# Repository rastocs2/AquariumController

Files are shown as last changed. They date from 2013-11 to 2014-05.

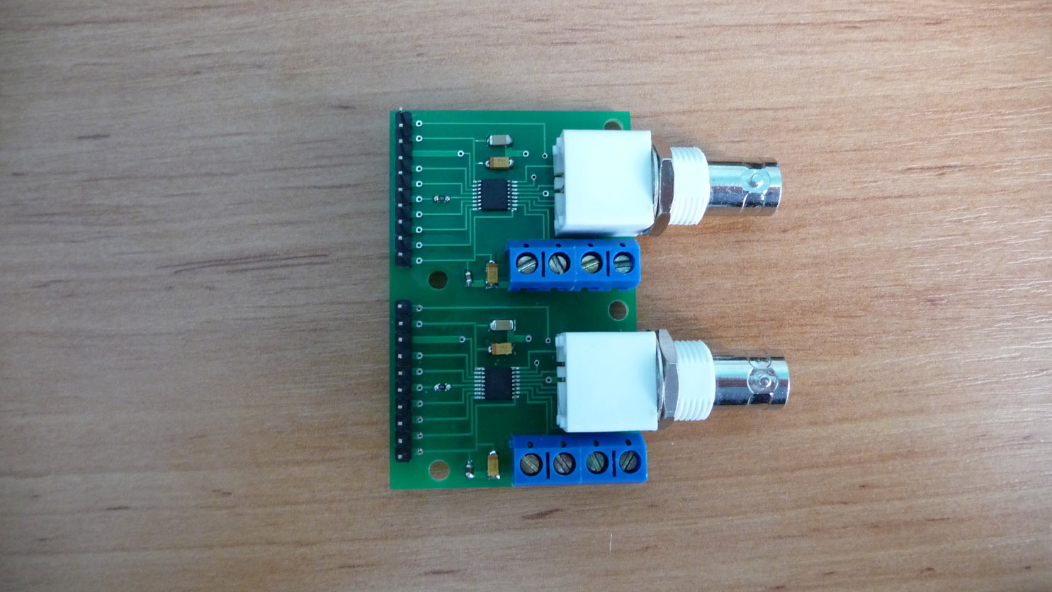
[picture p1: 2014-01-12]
Pics/pH_orp_module.jpg

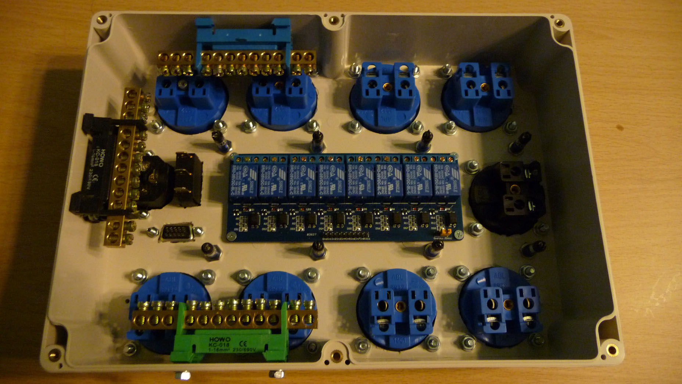
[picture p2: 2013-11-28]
Pics/power2.jpg

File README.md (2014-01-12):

AquariumController
==================

Aquarium controller based on Arduino and 4D Systems Intelligent Display Module.

## Components

1. Arduino Mega 2560 R3 (http://arduino.cc/en/Main/ArduinoBoardMega2560)
2. 4D Systems µLCD-28PTU (http://www.4dsystems.com.au/product/1/8/4D_Intelligent_Display_Modules/uLCD_28PTU/)
3. Real Time Clock Module DS3231 - it is much more accurate than DS1307 (http://www.ebay.com/sch/i.html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)
4. 8 Channel 5V Opto-Isolated Relay Module Shield (http://www.ebay.com/sch/i.html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)
5. Digital Temperature Sensor DS18B20 (http://www.ebay.com/sch/i.html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)
6. pH module based on LMP91200 (http://www.ti.com/product/lmp91200)
7. ORP module based on LMP91200 (http://www.ti.com/product/lmp91200)
8. WiFi module based on CC3000 (http://www.ti.com/product/cc3000) - will finished in version 3.0

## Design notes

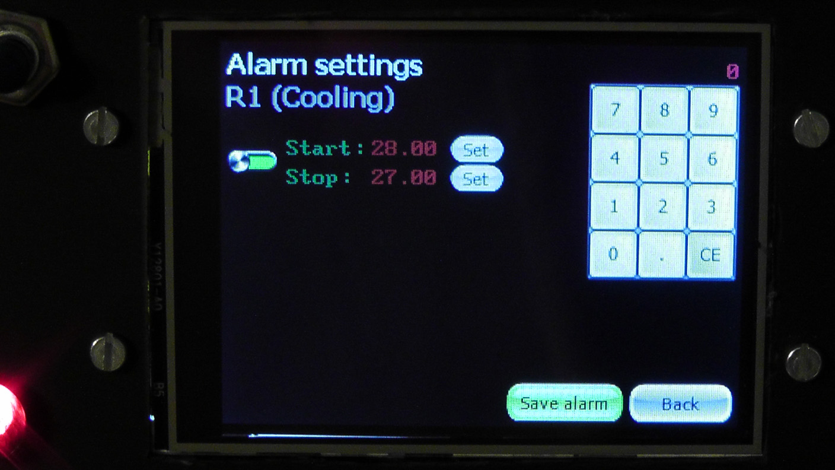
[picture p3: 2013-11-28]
Pics/lcd3.jpg

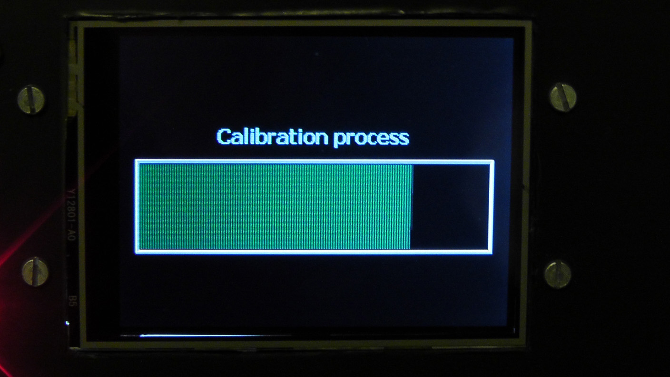
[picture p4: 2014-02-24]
Pics/lcd6.jpg

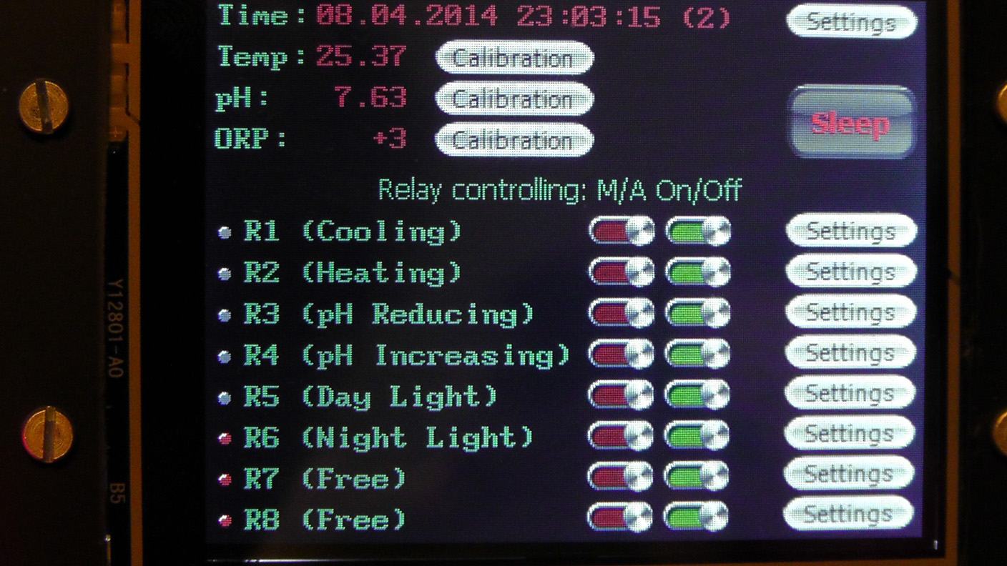
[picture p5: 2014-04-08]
Pics/lcd1.jpg

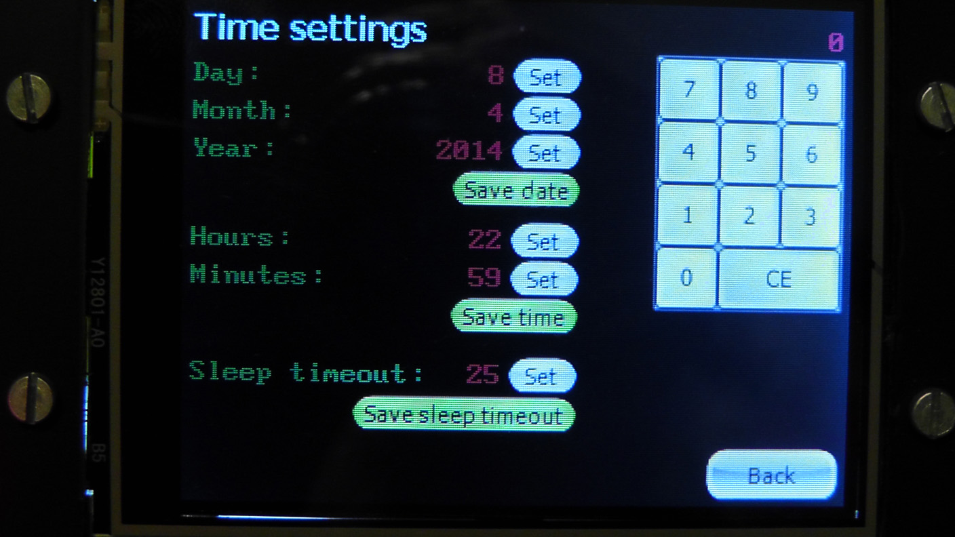
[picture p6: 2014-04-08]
Pics/lcd2.jpg

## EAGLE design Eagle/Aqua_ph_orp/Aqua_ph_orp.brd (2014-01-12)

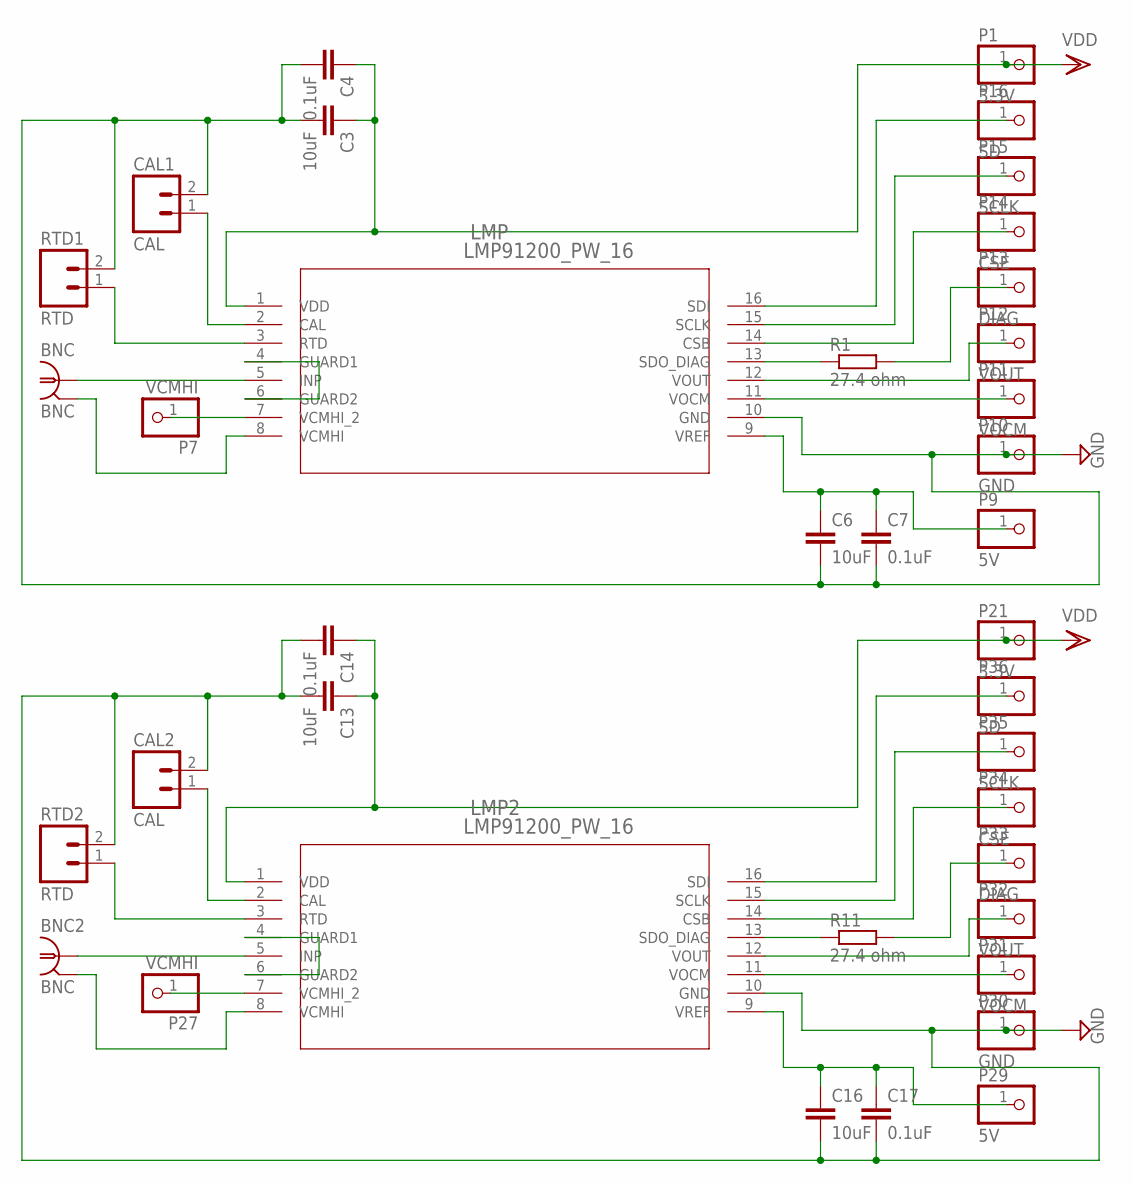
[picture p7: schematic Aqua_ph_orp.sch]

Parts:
BNC, BNC2: BNC; AMP_227161
C3, C6, C13, C16: 10uF; C3216
C4, C14: 0.1uF; C0603
C7, C17: 0.1uF; C1206
CAL1, CAL2: CAL; SCREWTERMINAL-KF-301-2P
LMP, LMP2: LMP91200_PW_16; MTC16
P1, P21: 3.3V; 1X01
P7, P27: VCMHI; 1X01
P9, P29: 5V; 1X01
P10, P30: GND; 1X01
P11, P31: VOCM; 1X01
P12, P32: VOUT; 1X01
P13, P33: DIAG; 1X01
P14, P34: CSE; 1X01
P15, P35: SCLK; 1X01
P16, P36: SD; 1X01
R1, R11: 27.4 ohm; R0603
RTD1, RTD2: RTD; SCREWTERMINAL-KF-301-2P

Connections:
GND: C3.2, C4.2, C6.2, C7.2, C13.2, C14.2, C16.2, C17.2, CAL1.2, CAL2.2, LMP.10 (GND), LMP2.10 (GND), P10.1, P30.1, RTD1.2, RTD2.2
unnamed: LMP.7 (VCMHI_2), P7.1
unnamed: BNC.2 (GND), LMP.8 (VCMHI)
unnamed: LMP.4 (GUARD1), LMP.6 (GUARD2)
unnamed: CAL1.1, LMP.2 (CAL)
unnamed: LMP.3 (RTD), RTD1.1
unnamed: C6.1, C7.1, LMP.9 (VREF), P9.1
unnamed: LMP2.14 (CSB), P34.1
unnamed: LMP2.15 (SCLK), P35.1
unnamed: LMP2.16 (SDI), P36.1
unnamed: LMP2.12 (VOUT), P32.1
unnamed: P33.1, R11.2
unnamed: LMP2.11 (VOCM), P31.1
unnamed: LMP2.13 (SDO_DIAG), R11.1
unnamed: BNC2.1, LMP2.5 (INP)
unnamed: LMP2.7 (VCMHI_2), P27.1
unnamed: BNC2.2 (GND), LMP2.8 (VCMHI)
unnamed: LMP2.4 (GUARD1), LMP2.6 (GUARD2)
unnamed: CAL2.1, LMP2.2 (CAL)
unnamed: LMP2.3 (RTD), RTD2.1
unnamed: C16.1, C17.1, LMP2.9 (VREF), P29.1
unnamed: LMP.14 (CSB), P14.1
unnamed: LMP.15 (SCLK), P15.1
unnamed: LMP.16 (SDI), P16.1
unnamed: LMP.12 (VOUT), P12.1
unnamed: P13.1, R1.2
unnamed: LMP.11 (VOCM), P11.1
unnamed: LMP.13 (SDO_DIAG), R1.1
unnamed: BNC.1, LMP.5 (INP)
VDD: C3.1, C4.1, C13.1, C14.1, LMP.1 (VDD), LMP2.1 (VDD), P1.1, P21.1

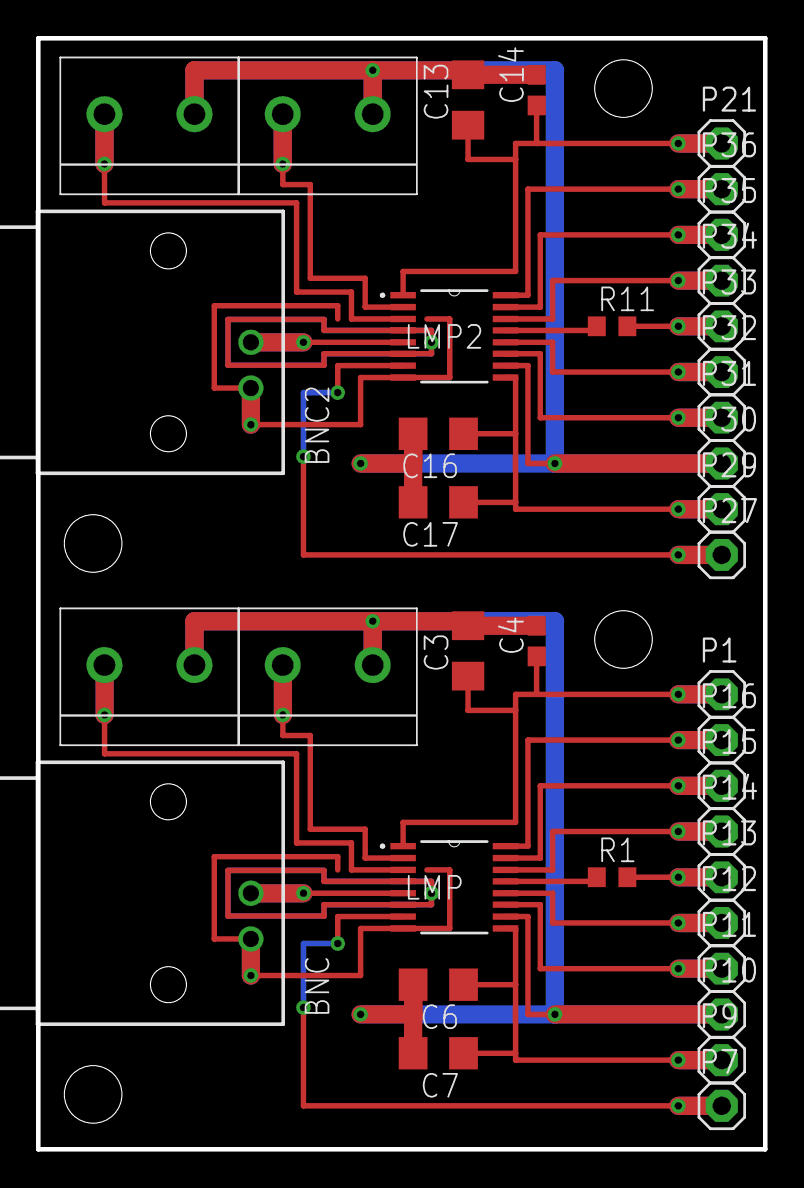
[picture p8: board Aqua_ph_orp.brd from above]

Board: 2 copper layers, 40.4 x 61.7 mm, 38 parts (0 on the bottom side), 30 nets.

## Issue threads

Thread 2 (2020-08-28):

Accuracy of ph / orp module

trancefreak77, 2020-08-28:
Hi,
I also want to use the LMP91200 to measure ph and redox voltage. Does your pcb design produce accurate results for both values (ph/orp)?

I plan to use the board to measure my pool water, so it needs to be very accurate.

Regards,
Christian

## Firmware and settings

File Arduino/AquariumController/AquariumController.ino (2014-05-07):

/*
  Project: Aquarium Controller
  Version: 2.1
  Author: Rastislav Birka
*/

#include <avr/sleep.h>
#include <avr/power.h>
#include <avr/wdt.h>
#include <genieArduino.h>

#include "AquariumController.h"
#include "AQUA_relay.h"
#include "AQUA_time.h"
#include "AQUA_temp.h"
#include "AQUA_ph.h"
#include "AQUA_orp.h"
#include "AQUA_lcd.h"

AQUA_temp   objTEMP;
AQUA_ph     objPH;
AQUA_orp    objORP;
AQUA_time   objTIME;
AQUA_relay  objRELAY;
AQUA_lcd    objLCD;
Genie       objGenie;

static uint8_t relayCount = AQUA_RELAY_ALARMS + AQUA_RELAY_TIMERS;
bool wakeup, wakeupButton, wakeupLCD;
unsigned long inactivity = 0, calWV = 0;
String keyboardString;
bool keyboardStart = true;
AQUA_datetime settingsDatetime;
uint16_t settingsTimeout;
uint8_t settingsRelay;
uint8_t calibration = GENIE_CALIBRATION_OFF;
AQUA_relayAlarm settingsAlarm;
AQUA_relayTimerPart settingsTimer[AQUA_RELAY_TIMER_PARTS];
AQUA_tempCalibrationPoint tempCalPoint[AQUA_TEMP_CALIBRATE_POINTS];
AQUA_phCalibrationPoint phCalPoint[AQUA_PH_CALIBRATE_POINTS];
AQUA_orpCalibrationPoint orpCalPoint[AQUA_ORP_CALIBRATE_POINTS];

/*** setup Watchdog Timer ***/
void setupWDT() {
  MCUSR &= ~(1<<WDRF); //clear reset flag
  WDTCSR |= (1<<WDCE) | (1<<WDE); //in order to change WDE or prescaler, need to set WDCE
  WDTCSR = 1<<WDP0 | 1<<WDP3; //set new watchdog timeout prescaler value (8.0 seconds)
  WDTCSR |= _BV(WDIE); //enable WD interrupt (note no reset)
}

/*** Watchdog Interrupt Service (is executed when watchdog timed out) ***/
ISR(WDT_vect) {
  wakeup = 1;
}

/*** Interrupt 0 Service (pin 2) ***/
void pin2Interrupt() {
  detachInterrupt(0);
  wakeupButton = 1;
}

/*** enters arduino into sleep mode ***/
void enterSleep() {
  if(AQUA_DEBUG_MODE_ON == 1) {
    Serial.println("");Serial.println("Sleep...");
  }
  digitalWrite(AQUA_ACTIVITY_LED, LOW);
  attachInterrupt(0, pin2Interrupt, LOW);
  delay(100);

  set_sleep_mode(SLEEP_MODE_PWR_DOWN);
  sleep_enable();
  sleep_mode();

  //program will continue from here after WDT timeout
  sleep_disable(); //first thing to do is disable sleep

  digitalWrite(AQUA_ACTIVITY_LED, HIGH);
  if(AQUA_DEBUG_MODE_ON == 1) {
    Serial.println("");Serial.println("Wakeup...");
  }
}

/*** display form ***/
void displayForm(uint8_t form, uint8_t index = 0, bool actualValues = false) {
  char row[8];
  uint8_t actualCalibration = calibration;
  AQUA_tempCalibrationPoint tempCalPointOld;
  AQUA_phCalibrationPoint phCalPointOld;
  AQUA_orpCalibrationPoint orpCalPointOld;

  if(AQUA_DEBUG_MODE_ON == 1) {
    Serial.print("displayForm: ");Serial.println(form);
  }
  objLCD.setActualForm(form);
  objGenie.WriteObject(GENIE_OBJ_FORM, form, 0);
  switch(form) {
    case GENIE_FORM_CALIBRATION:
      keyboardStart = true;
      keyboardString = "0";
      calibration = index - GENIE_CALIBRATION_TEMP;
      objGenie.WriteObject(GENIE_OBJ_STRINGS, GENIE_STR_INFO_CALIBRATION, 0);
      objGenie.WriteObject(GENIE_OBJ_STRINGS, GENIE_STR_CAL_INFO, index - GENIE_BTN_CALIBRATION_TEMP);
      sprintf(row, "%5d\0", 0);
      objGenie.WriteStr(GENIE_STR_CAL_KEY, row);
      if(calibration == GENIE_CALIBRATION_TEMP) {
        for(uint8_t i = 0; i < AQUA_TEMP_CALIBRATE_POINTS; i++) {
          tempCalPointOld = objTEMP.readCalibrationPoint(i);
          if(actualValues == false) {
            tempCalPoint[i].state = tempCalPointOld.state;
            tempCalPoint[i].refValue = tempCalPointOld.refValue;
            tempCalPoint[i].actValue = 0;
          }
          objGenie.WriteObject(GENIE_OBJ_4DBUTTON, i + GENIE_BTN_CAL1_STATE, tempCalPoint[i].state);
          sprintf(row, "%2d.%02d\0", (int)tempCalPointOld.refValue, (int)(tempCalPointOld.refValue*100)%100);
          objGenie.WriteStr(i + GENIE_STR_CAl1_REF_OLD, row);
          sprintf(row, "%2d.%02d\0", (int)tempCalPointOld.actValue, (int)(tempCalPointOld.actValue*100)%100);
          objGenie.WriteStr(i + GENIE_STR_CAl1_ACT_OLD, row);
          sprintf(row, "%2d.%02d\0", (int)tempCalPoint[i].refValue, (int)(tempCalPoint[i].refValue*100)%100);
          objGenie.WriteStr(i + GENIE_STR_CAl1_REF_NEW, row);
          sprintf(row, "%2d.%02d\0", (int)tempCalPoint[i].actValue, (int)(tempCalPoint[i].actValue*100)%100);
          objGenie.WriteStr(i + GENIE_STR_CAl1_ACT_NEW, row);
        }
      } else if(calibration == GENIE_CALIBRATION_PH) {
        for(uint8_t i = 0; i < AQUA_PH_CALIBRATE_POINTS; i++) {
          phCalPointOld = objPH.readCalibrationPoint(i);
          if(actualValues == false) {
            phCalPoint[i].state = phCalPointOld.state;
            phCalPoint[i].refValue = phCalPointOld.refValue;
            phCalPoint[i].actValue = 0;
          }
          objGenie.WriteObject(GENIE_OBJ_4DBUTTON, i + GENIE_BTN_CAL1_STATE, phCalPoint[i].state);
          sprintf(row, "%2d.%02d\0", (int)phCalPointOld.refValue, (int)(phCalPointOld.refValue*100)%100);
          objGenie.WriteStr(i + GENIE_STR_CAl1_REF_OLD, row);
          sprintf(row, "%2d.%02d\0", (int)phCalPointOld.actValue, (int)(phCalPointOld.actValue*100)%100);
          objGenie.WriteStr(i + GENIE_STR_CAl1_ACT_OLD, row);
          sprintf(row, "%2d.%02d\0", (int)phCalPoint[i].refValue, (int)(phCalPoint[i].refValue*100)%100);
          objGenie.WriteStr(i + GENIE_STR_CAl1_REF_NEW, row);
          sprintf(row, "%2d.%02d\0", (int)phCalPoint[i].actValue, (int)(phCalPoint[i].actValue*100)%100);
          objGenie.WriteStr(i + GENIE_STR_CAl1_ACT_NEW, row);
        }
      } else if(calibration == GENIE_CALIBRATION_ORP) {
        for(uint8_t i = 0; i < AQUA_ORP_CALIBRATE_POINTS; i++) {
          orpCalPointOld = objORP.readCalibrationPoint(i);
          if(actualValues == false) {
            orpCalPoint[i].state = orpCalPointOld.state;
            orpCalPoint[i].refValue = orpCalPointOld.refValue;
            orpCalPoint[i].actValue = 0;
          }
          objGenie.WriteObject(GENIE_OBJ_4DBUTTON, i + GENIE_BTN_CAL1_STATE, orpCalPoint[i].state);
          sprintf(row, "%+5d\0", (int)orpCalPointOld.refValue);
          objGenie.WriteStr(i + GENIE_STR_CAl1_REF_OLD, row);
          sprintf(row, "%+5d\0", (int)orpCalPointOld.actValue);
          objGenie.WriteStr(i + GENIE_STR_CAl1_ACT_OLD, row);
          sprintf(row, "%+5d\0", (int)orpCalPoint[i].refValue);
          objGenie.WriteStr(i + GENIE_STR_CAl1_REF_NEW, row);
          sprintf(row, "%+5d\0", (int)orpCalPoint[i].actValue);
          objGenie.WriteStr(i + GENIE_STR_CAl1_ACT_NEW, row);
        }
      }
      break;
    case GENIE_FORM_CALIBRATION_SHOW:
      calibration = GENIE_CALIBRATION_OFF;
      objGenie.WriteObject(GENIE_OBJ_GAUGE, GENIE_GAUGE_CALIBRATION, 0);
      if(actualCalibration == GENIE_CALIBRATION_TEMP) {
        float temp = objTEMP.getTemp(1);
        for(uint8_t i = 1; i < 10; i++) {
          objGenie.WriteObject(GENIE_OBJ_GAUGE, GENIE_GAUGE_CALIBRATION, i*10);
          temp+= objTEMP.getTemp(1);
        }
        objGenie.WriteObject(GENIE_OBJ_GAUGE, GENIE_GAUGE_CALIBRATION, 100);
        tempCalPoint[index - GENIE_BTN_CAL1_READ_ACT].actValue = temp/10.00;
        displayForm(GENIE_FORM_CALIBRATION, GENIE_BTN_CALIBRATION_TEMP, true);
      } else if(actualCalibration == GENIE_CALIBRATION_PH) {
        float pH = objPH.getPH(1);
        for(uint8_t i = 1; i < 100; i++) {
          objGenie.WriteObject(GENIE_OBJ_GAUGE, GENIE_GAUGE_CALIBRATION, i);
          pH+= objPH.getPH(1);
        }
        objGenie.WriteObject(GENIE_OBJ_GAUGE, GENIE_GAUGE_CALIBRATION, 100);
        phCalPoint[index - GENIE_BTN_CAL1_READ_ACT].actValue = pH/100.00;
        displayForm(GENIE_FORM_CALIBRATION, GENIE_BTN_CALIBRATION_PH, true);
      } else if(actualCalibration == GENIE_CALIBRATION_ORP) {
        int orp = objORP.getORP(1);
        for(uint8_t i = 1; i < 100; i++) {
          objGenie.WriteObject(GENIE_OBJ_GAUGE, GENIE_GAUGE_CALIBRATION, i);
          orp+= objORP.getORP(1);
        }
        objGenie.WriteObject(GENIE_OBJ_GAUGE, GENIE_GAUGE_CALIBRATION, 100);
        orpCalPoint[index - GENIE_BTN_CAL1_READ_ACT].actValue = (int)(orp/100);
        displayForm(GENIE_FORM_CALIBRATION, GENIE_BTN_CALIBRATION_ORP, true);
      }
      break;
    case GENIE_FORM_SET_TIMER:
      keyboardStart = true;
      keyboardString = "0";
      settingsRelay = index - GENIE_BTN_SET_R1;
      objGenie.WriteObject(GENIE_OBJ_STRINGS, GENIE_STR_INFO_TIMER, 0);
      objGenie.WriteObject(GENIE_OBJ_STRINGS, GENIE_STR_TIMER_INFO, settingsRelay - AQUA_RELAY_TIMERS);
      sprintf(row, "%5d\0", 0);
      objGenie.WriteStr(GENIE_STR_TIMER_KEY, row);
      for(uint8_t i = 0; i < AQUA_RELAY_TIMER_PARTS; i++) {
        settingsTimer[i] = objRELAY.readRelayTimerPart(settingsRelay, i);
        sprintf(row, "%2d:%02d\0", (int)(settingsTimer[i].from/60), settingsTimer[i].from%60);
        objGenie.WriteStr(i*2 + GENIE_STR_TIMER1_START, row);
        sprintf(row, "%2d:%02d\0", (int)(settingsTimer[i].to/60), settingsTimer[i].to%60);
        objGenie.WriteStr(i*2 + GENIE_STR_TIMER1_STOP, row);
        objGenie.WriteObject(GENIE_OBJ_4DBUTTON, i + GENIE_BTN_TIMER1_STATE, settingsTimer[i].state);
      }
      break;
    case GENIE_FORM_SET_ALARM:
      keyboardStart = true;
      keyboardString = "0";
      settingsRelay = index - GENIE_BTN_SET_R1;
      settingsAlarm = objRELAY.readRelayAlarm(settingsRelay);
      objGenie.WriteObject(GENIE_OBJ_STRINGS, GENIE_STR_INFO_ALARM, 0);
      objGenie.WriteObject(GENIE_OBJ_STRINGS, GENIE_STR_ALARM_INFO, settingsRelay);
      objGenie.WriteObject(GENIE_OBJ_4DBUTTON, GENIE_BTN_ALARM_STATE, settingsAlarm.state);
      sprintf(row, "%5d\0", 0);
      objGenie.WriteStr(GENIE_STR_ALARM_KEY, row);
      sprintf(row, "%2d.%02d\0", (int)(settingsAlarm.start/100), settingsAlarm.start%100);
      objGenie.WriteStr(GENIE_STR_ALARM_START, row);
      sprintf(row, "%2d.%02d\0", (int)(settingsAlarm.stop/100), settingsAlarm.stop%100);
      objGenie.WriteStr(GENIE_STR_ALARM_STOP, row);
      break;
    case GENIE_FORM_SET_TIME:
      keyboardStart = true;
      keyboardString = "0";
      settingsDatetime = objTIME.getDateTime();
      settingsTimeout = objLCD.getTimeout();
      objGenie.WriteObject(GENIE_OBJ_STRINGS, GENIE_STR_INFO_TIME, 0);
      sprintf(row, "%5d\0", 0);
      objGenie.WriteStr(GENIE_STR_TIME_KEY, row);
      sprintf(row, "%4d\0", settingsDatetime.day);
      objGenie.WriteStr(GENIE_STR_DAY, row);
      sprintf(row, "%4d\0", settingsDatetime.mon);
      objGenie.WriteStr(GENIE_STR_MONTH, row);
      sprintf(row, "%4d\0", settingsDatetime.year);
      objGenie.WriteStr(GENIE_STR_YEAR, row);
      sprintf(row, "%4d\0", settingsDatetime.hour);
      objGenie.WriteStr(GENIE_STR_HOUR, row);
      sprintf(row, "%4d\0", settingsDatetime.min);
      objGenie.WriteStr(GENIE_STR_MIN, row);
      sprintf(row, "%4d\0", settingsTimeout);
      objGenie.WriteStr(GENIE_STR_SLEEP_TIMEOUT, row);
      break;
    case GENIE_FORM_SLEEP:
      objGenie.WriteContrast(0);
      wakeupLCD = 0;
      break;
    case GENIE_FORM_MAIN:
    default:
      calibration = GENIE_CALIBRATION_OFF;
      break;
  }
}

/*** 4Dsystems event handler ***/
void lcdEventHandler(void) {
  char row[8];
  long iValue;
  genieFrame Event;
  objGenie.DequeueEvent(&Event);

  if(AQUA_DEBUG_MODE_ON == 1) {
    Serial.println("----------");
    Serial.print("cmd:      ");Serial.println(Event.reportObject.cmd);
    Serial.print("object:   ");Serial.println(Event.reportObject.object);
    Serial.print("index:    ");Serial.println(Event.reportObject.index);
    Serial.print("data_msb: ");Serial.println(Event.reportObject.data_msb);
    Serial.print("data_lsb: ");Serial.println(Event.reportObject.data_lsb);
    Serial.println("----------");
  }

  if(Event.reportObject.cmd == GENIE_REPORT_EVENT || Event.reportObject.cmd == GENIE_REPORT_OBJ) {
    wakeupLCD = 1;
    wakeup = 1;
    inactivity = millis();
  }
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
void loop() {
  objGenie.DoEvents();
  if(wakeupLCD == 1 && calibration > GENIE_CALIBRATION_OFF) {
    if(calWV < millis() - 500) {
      writeActualValue();
      calWV = millis();
    }
  }
  if(wakeupButton == 1) {
    wakeupButton = 0;
    wakeup = 1;
    inactivity = millis();
    if(AQUA_DEBUG_MODE_ON == 1) {
      Serial.println("");Serial.println("pin2Interrupt...");
    }
    if(wakeupLCD == 0) {
      displayForm(GENIE_FORM_MAIN);
      objGenie.WriteContrast(1);
      wakeupLCD = 1;
    }
  }
  if(wakeup == 1) {
    wakeup = 0;
    checkAll();
    if(wakeupLCD == 0) {
      enterSleep();
    }
  }
}

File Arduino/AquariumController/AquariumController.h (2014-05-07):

/*
  Project: Aquarium Controller
  Library: Constants
  Version: 2.1
  Author: Rastislav Birka
*/

#define AQUA_DEBUG_MODE_ON          0 //0-live application, 1-debug mode with print to serial
#define AQUA_ACTIVITY_LED          12 //pin where is led for indicate activity
#define AQUA_WAKEUP_BUTTON          2 //pin where is button for wakeup
#define AQUA_ANALOG_VREF         3300 //reference voltage for analog (mV)
#define AQUA_ADC_BIT_RESOLUTION    10 //ADC bit resolution (10 for arduino internal ADC)

#define AQUA_RELAY_FIRST_PIN       30 //for 8 relay module will use next 7 pins (30,...,37)
#define AQUA_RELAY_ALARMS           4 //number of alarms (temperature high, temperature low, pH high, pH low)
#define AQUA_RELAY_TIMERS           4 //number of timers (day light, night light, ...)
#define AQUA_RELAY_TIMER_PARTS      4 //number of timer parts (day light, night light, ...)
#define AQUA_RELAY_ALARMS_ADDR   0x00 //4 bytes for each alarm = 2 bytes for start value and 2 bytes for stop value (4 alarms = 16 bytes)
#define AQUA_RELAY_TIMERS_ADDR   0x10 //4 bytes for each timer part = 2 bytes for start timestamp and 2 bytes for end timestamp (4 timer parts for each timer = 16 timer parts = 64 bytes)

#define AQUA_TIME_DATA_PIN         22 //SDA pin
#define AQUA_TIME_CLOCK_PIN        23 //SCLK pin
#define AQUA_TIME_SQ_PIN           24 //SQ pin
#define AQUA_TIME_DS_PIN           25 //DS pin

#define AQUA_TEMP_DQ_PIN           26 //DQ pin
#define AQUA_TEMP_CALIBRATE_ADDR 0x50 //4 bytes for each calibration point = 2 bytes for reference value and 2 bytes for measured value (3 point calibration = 12 bytes)
#define AQUA_TEMP_CALIBRATE_POINTS  3 //number of calibrating points
#define AQUA_TEMP_RELAY_COOLING     0 //cooling
#define AQUA_TEMP_RELAY_HEATING     1 //heating

#define AQUA_PH_DQ_PIN             27 //DQ pin
#define AQUA_PH_CALIBRATE_ADDR   0x60 //4 bytes for each calibration point = 2 bytes for reference value and 2 bytes for measured value (3 point calibration = 12 bytes)
#define AQUA_PH_CALIBRATE_POINTS    3 //number of calibrating points
#define AQUA_PH_RELAY_REDUCTION     2 //pH reduction
#define AQUA_PH_RELAY_INCREASE      3 //pH increase
#define AQUA_PH_VOUT_PIN            0 //VOUT pin - Analog Output
#define AQUA_PH_VOCM_PIN            1 //VOCM pin - Output common mode voltage

#define AQUA_ORP_DQ_PIN            28 //DQ pin
#define AQUA_ORP_CALIBRATE_ADDR  0x70 //4 bytes for each calibration point = 2 bytes for reference value and 2 bytes for measured value (3 point calibration = 12 bytes)
#define AQUA_ORP_CALIBRATE_POINTS   3 //number of calibrating points
#define AQUA_ORP_VOUT_PIN           4 //VOUT pin - Analog Output
#define AQUA_ORP_VOCM_PIN           5 //VOCM pin - Output common mode voltage

#define AQUA_LCD_DEFAULT_TIMEOUT   30 //timeout for display sleep mode in seconds
#define AQUA_LCD_TIMEOUT_ADDR    0x80 //2 bytes for lcd timeout in seconds
#define AQUA_LCD_SERIAL             2 //which serial port is used for LCD //1 = pin 19(RX) and pin 18(TX), 2 = pin 17(RX) and pin 16(TX), 3 = pin 15(RX) and pin 14(TX)
#define AQUA_LCD_SERIAL_SPEED  115200 //speed for serial communication
#define AQUA_LCD_RESET_PIN          4 //pin for reset

#define AQUA_SPI_MISO_PIN          50 //SPI MISO pin
#define AQUA_SPI_MOSI_PIN          51 //SPI MOSI pin
#define AQUA_SPI_SCLK_PIN          52 //SPI SCLK pin
#define AQUA_SPI_SS_PIN            53 //SPI SS pin
#define AQUA_SPI_PH_VOUT_PIN       49 //pH VOUT pin (ADC141S626)
#define AQUA_SPI_ORP_VOUT_PIN      48 //ORP VOUT pin (ADC141S626)

#define AQUA_ADS1115_SDA_PIN       46 //SDA pin
#define AQUA_ADS1115_SCL_PIN       47 //SCL pin

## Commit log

2014-01-12 version 2.0 - added pH and ORP module
    [Aqua_ph_orp.brd, Aqua_ph_orp.sch]
2014-02-24 new form for calibration process + cleanup
2014-03-03 changed VREF to 3.3V (for LMP91200 changed also VDD to 3.3V)
2014-04-01 fix in DST calculation
    [AQUA_time.cpp]

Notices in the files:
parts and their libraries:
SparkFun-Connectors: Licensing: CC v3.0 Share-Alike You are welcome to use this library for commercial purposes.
